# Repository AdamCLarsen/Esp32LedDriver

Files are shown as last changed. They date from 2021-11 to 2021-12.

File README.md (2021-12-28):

# Esp32 LED Driver

An ESP32 LED Driver for use with [ESPHome](https://esphome.io/index.html).  Supports 12 volt and 24 volt LEDs.

### NOTE:

This was a fun project I did for myself, where I added a few minor things I wanted, and maybe you will learn something from what I put together. However after I finished by baord, I found QuinLED, I recommend you go look at [QuinLED-An-Deca](https://quinled.info/quinled-an-deca/) over having my board manufactured.

## Goals

* Work with 24 Volt LEDs, at least 1.5 amps
* Independed control of two RGB-W strips, or eight white LED Strips
* Work well with Home Assistant
* Built in power monitoring
* Price is $50 to $75 per board

## Pin assignment on ESP32

* Test LED - ~IO19 (was ~IO13 in V1)
* SDA - IO21
* SCL - IO22
* INA219 - i2c address - 45
* CHAN 1 - IO32
* CHAN 2 - IO33
* CHAN 3 - IO25
* CHAN 4 - IO26
* CHAN 5 - IO27
* CHAN 6 - IO18
* CHAN 7 - IO17
* CHAN 8 - IO16

## The result

esp32



## Case

I have designed a case for it as well over on [OnShape](https://cad.onshape.com/documents/408e2383d926b3595b2bb312/w/fd92e074be70698e5e0da078/e/0ab2fa066dd2b40c54c9b8b1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) for use with a 3D printer.

Print uses M3 3D Printing Brass Nuts, 5mm x 6mm Embedment.  Found them on [Amazon here](https://www.amazon.com/gp/product/B09KZSJS88/).

Full Assembly

## Other resources

* [WLED](https://kno.wled.ge/) Software that also runs on ESP32 and should work on this board using the Analog controls, if you don't have HA or don't use ESPHome.
* [QuinLED-An-Deca](https://quinled.info/quinled-an-deca/) Use this board over my board.

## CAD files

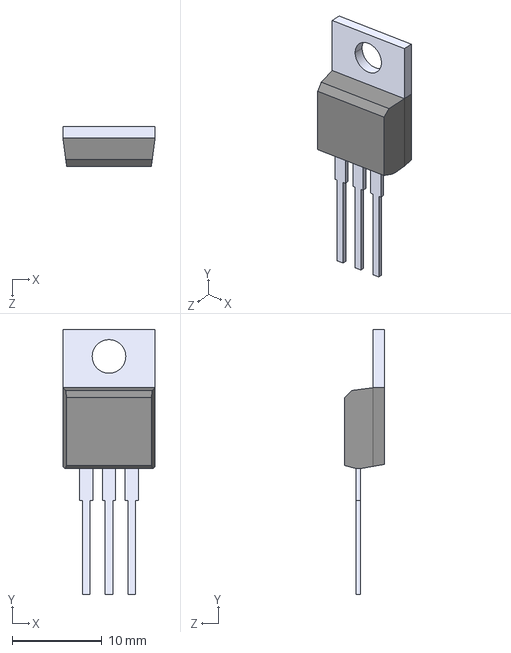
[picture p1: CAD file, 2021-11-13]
KiCad-Project/ESP32/IRF520/IRF520.step
10.3 x 29.5 x 4.45 mm

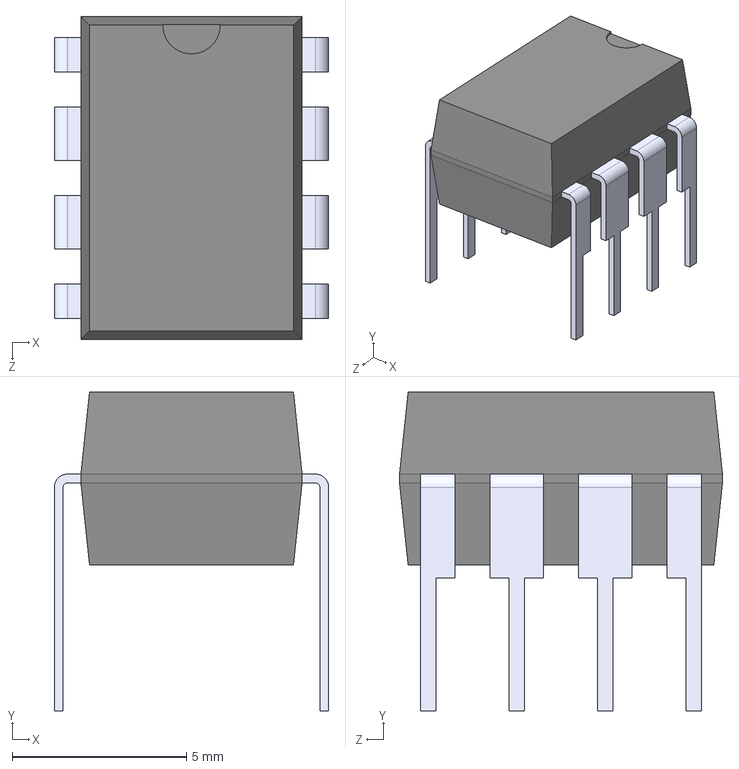
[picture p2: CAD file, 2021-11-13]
KiCad-Project/ESP32/TC4420CPA/TC4420CPA.step
7.87 x 9.14 x 9.27 mm

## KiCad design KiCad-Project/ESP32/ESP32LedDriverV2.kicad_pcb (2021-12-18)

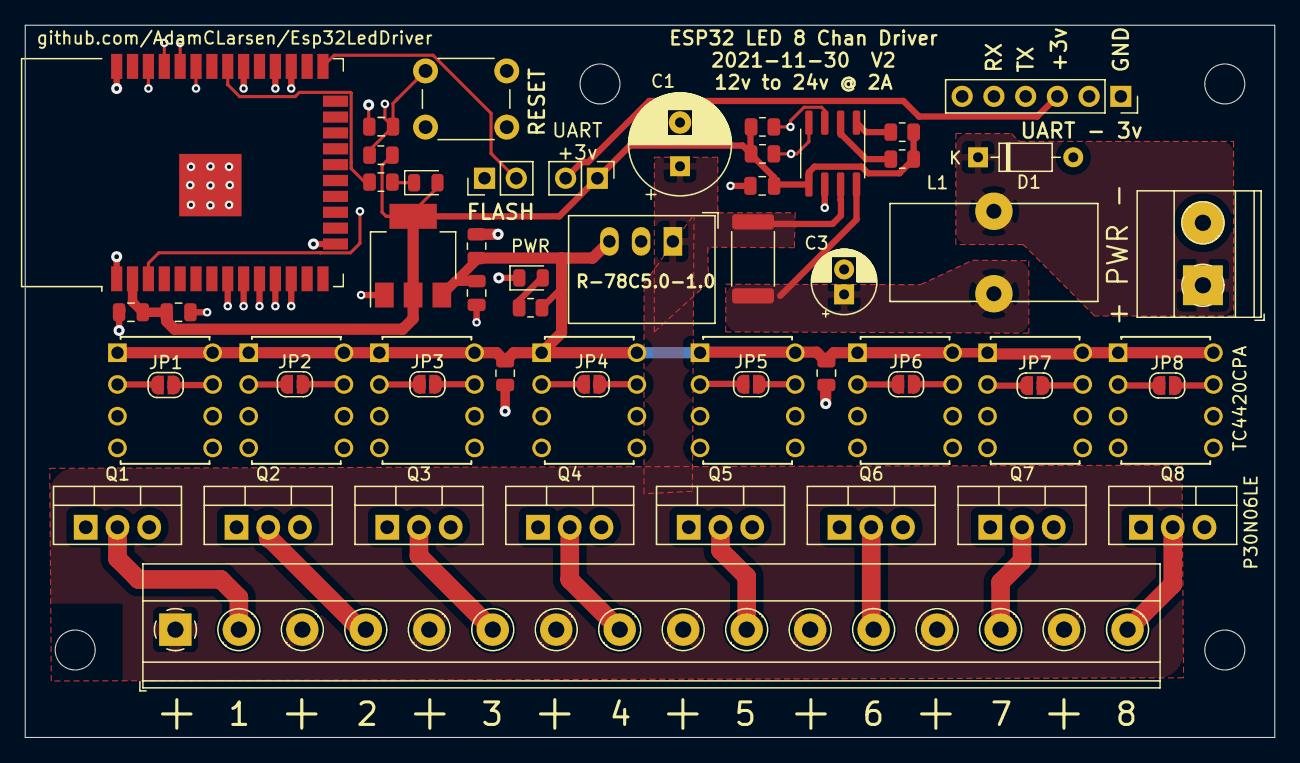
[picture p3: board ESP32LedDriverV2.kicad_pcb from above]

Board: 4 copper layers, 100.0 x 57.0 mm, 60 parts (0 on the bottom side), 42 nets.

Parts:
C1: 330uF; CP_Radial_D8.0mm_P3.50mm
C2, C6, C9: 0.1uF; C_0805_2012Metric
C3: 100uF; CP_Radial_D5.0mm_P2.00mm
C4: 1uF; C_0805_2012Metric
C5, C7, C8: 22uF; C_0805_2012Metric
C10: 10uf; C_0805_2012Metric
D1: D_Zener 25v; D_DO-35_SOD27_P7.62mm_Horizontal
H1, H2, H3, H4: MountingHole; MountingHole_3.2mm_M3
J1: Power; TerminalBlock_Phoenix_MKDS-1,5-2_1x02_P5.00mm_Horizontal
J2: LED Terminal; TerminalBlock_Phoenix_MKDS-1,5-16-5.08_1x16_P5.08mm_Horizon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
J3: UART; PinSocket_1x06_P2.54mm_Vertical
JP1, JP2, JP3, JP4, JP5, JP6, JP7, JP8: Driver Bypass; SolderJumper-2_P1.3mm_Open_RoundedPad1.0x1.5mm
JP9: FLASH; PinHeader_1x02_P2.54mm_Vertical
JP10: UART_VCC; PinHeader_1x02_P2.54mm_Vertical
L1: 100uH; L_Toroid_Vertical_L16.4mm_W7.6mm_P6.60mm_Vishay_TJ3
LED1: PWR LED; LED_0805_2012Metric
LED2: IO13_LED; LED_0805_2012Metric
Q1, Q2, Q3, Q4, Q5, Q6, Q7, Q8: P30N06LE; TO-220-3_Vertical
R1: 0.1Ω 1% 1W; R_2512_6332Metric
R2, R3, R4, R5, R7: 10K; R_0805_2012Metric
R6: 2.2K; R_0805_2012Metric
R8: 200; R_0805_2012Metric
SW1: RESET; SW_PUSH_6mm
U1: R-78C5.0-1.0; Converter_DCDC_RECOM_R-78E-0.5_THT
U2: INA219AxD; SOIC-8_3.9x4.9mm_P1.27mm
U3, U4, U5, U6, U7, U8, U9, U10: TC4420CPA; DIP254P762X533-8
U11: AMS1117-3.3; SOT-223-3_TabPin2
U12: ESP32-WROOM-32

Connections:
+3V3: C2.1, C9.1, C10.1, JP10.1, LED2.2, R2.1, R3.1, R4.1, R5.1, R7.1, U2.5, U11.2, U12.2
+5V: C4.1, C5.1, C7.1, C8.1, R6.1, U1.3, U3.1, U3.8, U4.1, U4.8, U5.1, U5.8, U6.1, U6.8, U7.1, U7.8, U8.1, U8.8, U9.1, U9.8, U10.1, U10.8, U11.3
+24V: C1.1, J2.1, J2.3, J2.5, J2.7, J2.9, J2.11, J2.13, J2.15, R1.1, U1.1, U2.7
+24V_IN: C3.1, L1.2, R1.2, U2.8
+24V_SW: D1.1, J1.1, L1.1
/ESP32/UART_RX: J3.4, U12.34
/ESP32/UART_TX: J3.5, U12.35
/ESP32/UART_VCC: J3.3, JP10.2
/ESP32/~FLASH: JP9.2, U12.25
/ESP32/~RESET: C6.1, R7.2, SW1.2, U12.3
/Z1: JP1.1, U3.2, U12.8
/Z1-: J2.2, Q1.2
/Z2: JP2.1, U4.2, U12.9
/Z2-: J2.4, Q2.2
/Z3: JP3.1, U5.2, U12.10
/Z3-: J2.6, Q3.2
/Z4: JP4.1, U6.2, U12.11
/Z4-: J2.8, Q4.2
/Z5: JP5.1, U7.2, U12.12
/Z5-: J2.10, Q5.2
/Z6: JP6.1, U8.2, U12.30
/Z6-: J2.12, Q6.2
/Z7: JP7.1, U9.2, U12.28
/Z7-: J2.14, Q7.2
/Z8: JP8.1, U10.2, U12.27
/Z8-: J2.16, Q8.2
GND: C1.2, C2.2, C3.2, C4.2, C5.2, C6.2, C7.2, C8.2, C9.2, C10.2, D1.2, J1.2, J3.1, JP9.1, LED1.1, Q1.3, Q2.3, Q3.3, Q4.3, Q5.3, Q6.3, Q7.3, Q8.3, SW1.1, U1.2, U2.6, U3.4, U3.5, U4.4, U4.5, U5.4, U5.5, U6.4, U6.5, U7.4, U7.5, U8.4, U8.5, U9.4, U9.5, U10.4, U10.5, U11.1, U12.1, U12.15, U12.38, U12.39
unnamed: JP1.2, Q1.1, U3.7
unnamed: JP2.2, Q2.1, U4.7
unnamed: JP3.2, Q3.1, U5.7
unnamed: JP4.2, Q4.1, U6.7
unnamed: JP5.2, Q5.1, U7.7
unnamed: JP6.2, Q6.1, U8.7
unnamed: JP7.2, Q7.1, U9.7
unnamed: JP8.2, Q8.1, U10.7
unnamed: LED1.2, R6.2
unnamed: LED2.1, R8.2
unnamed: R4.2, U2.1
unnamed: R5.2, U2.2
unnamed: R8.1, U12.31
SCL: R3.2, U2.4, U12.36
SDA: R2.2, U2.3, U12.33

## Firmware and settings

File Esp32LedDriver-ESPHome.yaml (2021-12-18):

esphome:
  name: Esp32LedDriver
  platform: ESP32
  board: esp32dev
  
# Enable logging
logger:

# Enable Home Assistant API
api:

wifi:
  ssid: ""
  password: ""

web_server:

i2c:
  sda: 21
  scl: 22
  scan: true
  id: bus_a
  
output:
  - platform: ledc
    pin: GPIO16
    id: driver8
    frequency: 20000Hz
  - platform: ledc
    pin: GPIO17
    id: driver7
    frequency: 20000Hz
  - platform: ledc
    pin: GPIO18
    id: driver6
    frequency: 20000Hz
  - platform: ledc
    pin: GPIO27
    id: driver5
    frequency: 20000Hz
  - platform: ledc
    pin: GPIO26
    id: driver4
    frequency: 20000Hz
  - platform: ledc
    pin: GPIO25
    id: driver3
    frequency: 20000Hz
  - platform: ledc
    pin: GPIO33
    id: driver2
    frequency: 20000Hz
  - platform: ledc
    pin: GPIO32
    id: driver1
    frequency: 20000Hz
  - platform: ledc
    pin: GPIO13  # Changed to GPIO19 on V2 boards
    inverted: true
    id: TestLED
    frequency: 20000Hz
 
# Example usage in a light
light:
  - platform: monochromatic
    output: driver1
    name: "driver1"
    default_transition_length: 500ms
  - platform: monochromatic
    output: driver2
    name: "driver2"
    default_transition_length: 500ms
  - platform: monochromatic
    output: driver3
    name: "driver3"
    default_transition_length: 500ms
  - platform: monochromatic
    output: driver4
    name: "driver4"
    default_transition_length: 500ms
  - platform: monochromatic
    output: driver5
    name: "driver5"
    default_transition_length: 500ms
  - platform: monochromatic
    output: driver6
    name: "driver6"
    default_transition_length: 500ms
  - platform: monochromatic
    output: driver7
    name: "driver7"
    default_transition_length: 500ms
  - platform: monochromatic
    output: driver8
    name: "driver8"
    default_transition_length: 500ms
  - platform: monochromatic
    output: TestLED
    name: "TestLED"
    default_transition_length: 500ms

sensor:
  - platform: ina219
    address: 0x45
    shunt_resistance: 0.1 ohm
    current:
      name: "Current"
    power:
      name: "Power"
    bus_voltage:
      name: "Voltage"
    shunt_voltage:
      name: "Shunt Voltage"
    max_voltage: 25.0V
    max_current: 3.2A
    update_interval: 10s

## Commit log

2021-11-13 Init Check-in
    [ESP32.sch, ESP32LedDriverV2.kicad_pcb, ESP32LedDriverV2.sch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]
2021-11-13 swap out 603 resistors for 805
    Give us more room to work with if we have to fix something.
    [ESP32.sch, ESP32LedDriverV2.kicad_pcb, ESP32LedDriverV2.sch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]
2021-11-13 Switch power direction detection to SMD
    [ESP32LedDriverV2.kicad_pcb, ESP32LedDriverV2.sch]
2021-11-14 Fixes in prep for printing
    Making sure tolerance are in-spec for JLC PCB
    [ESP32.sch, ESP32LedDriverV2.kicad_pcb, ESP32LedDriverV2.sch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]
2021-11-14 Fix Power Mosfet direction
    [ESP32LedDriverV2.kicad_pcb, ESP32LedDriverV2.sch]
2021-11-14 Fix pin header
    [ESP32.sch, ESP32LedDriverV2.kicad_pcb, LEDDriver.sch]
2021-11-15 Enable to bottom mask layer
    [ESP32LedDriverV2.kicad_pcb]
2021-11-15 Refine PCB layout
    Added GPIO labels to the bottom of the board
    updates to ESP32 power and ground traces
    Removed zip file of plot files.
    [ESP32LedDriverV2.kicad_pcb]
2021-11-16 Increased trace width for +24v net
    [ESP32LedDriverV2.kicad_pcb, LEDDriver.sch]
2021-12-01 Removed reverse voltage and increased size of power traces
    Reverse voltage needed different components for 24 volt, and was a nice to have, so to keep cost down, opted to remove it.
    [ESP32.sch, ESP32LedDriverV2.kicad_pcb, ESP32LedDriverV2.sch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]
2021-12-01 Jumper to connect UART VCC to 5v
    Allow powering the 3v-5v side from the UART conector.
    [ESP32.sch, ESP32LedDriverV2.kicad_pcb]
2021-12-02 Update fill zones
    [ESP32.sch, ESP32LedDriverV2.kicad_pcb]
2021-12-04 Move on board test LED to a better pin. and swap TX/RX UART pins
    [ESP32.sch, ESP32LedDriverV2.kicad_pcb, LEDDriver.sch]
2021-12-04 Aligning parts to each other
    [ESP32LedDriverV2.kicad_pcb, LEDDriver.sch]
2021-12-04 More clean up of PCB layout
    [ESP32LedDriverV2.kicad_pcb]
2021-12-16 update pin labels
    [ESP32.sch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]
2021-12-16 Reset annotations
    [ESP32.sch, ESP32LedDriverV2.kicad_pcb, ESP32LedDriverV2.sch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]
2021-12-18 Added ESPHome Yaml
    [ESP32LedDriverV2.kicad_pcb]
